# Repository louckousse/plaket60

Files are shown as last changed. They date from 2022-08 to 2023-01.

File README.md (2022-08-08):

# Plaket60
## Based on [Plain60 Flex Edition rev2.2](https://github.com/evyd13/plain60-flex-edition)

### Modification from Plain60 Flex Edition rev2.2

- Removing the speaker
- Removing the usb port
- Removing the flex cut
- Removing some compatibility in layout (keeping a Tsangan bottom row)

### Features
- Compatible with QMK Firmware and VIA Configurator (if you flash a VIA compatible .hex file)
- Required JST header for connection with daughterboard
- ESD protection and fuse
- No LEDs and no underglow
- Minimal layout support
- ISP header

### Supported layouts
Supported layouts of the Plaket60 PCB

### Bill of materials (BOM)
Amount is per PCB, multiply as needed.

| LCSC part # | Description | Value | Package  | Amount |
| --- | --- | ----- | --- | ---:|
| C49678 | Capacitor | 0.1uF | 0805 | 4 |
| C1779 | Capacitor | 4.7uF | 0805 | 1 |
| C28323 | Capacitor | 1uF | 0805 | 1 |
| C109001 | Diode | | 0805 | 64 |
| C261942 | Fuse | | 0805 | 1 |
| C17414 | Resistor | 10K | 0805 | 2 |
| C212411 | Resistor | 5.1K  | 0805 | 2 |
| C17561 | Resistor | 22 | 0805 | 2 |
| C44854 | MCU | 32U4  | QFP-44 | 1 |
| C7519 | ESD chip | | SOT23-6  | 1 |
| C341521 | Resonator | 16MHz | SMD | 1 |
| C92584 | Switch | | SMD | 1 |
| C2845363 | JST | | SMD | 1 |

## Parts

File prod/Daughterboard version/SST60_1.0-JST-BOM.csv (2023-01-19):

Comment | Designator | Footprint | LCSC
1k | R_Crystal1,R_Flash1,R_RST1 | R_0402_1005Metric | C11702
SM04B | J1 | JST_SH_SM04B-SRSS-TB_1x04-1MP_P1.00mm_Horizontal | C145956
.1u | C_1V-Decoup2,C_1V-Decoup3,C_3V-Decoup3,C_3V-Decoup4,C_3V-Decoup5,C_3V-Decoup6,C_3V-Decoup7,C_3V-Decoup8,C_3V-Decoup9,C_Flash1 | C_0402_1005Metric | C1525
10u | C_3V-Decoup1 | C_0402_1005Metric | C15525
22pF | C_Crystal1,C_Crystal2 | C_0402_1005Metric | C1555
RP2040 | U1 | RP2040-QFN-56 | C2040
220 | R_LED1,R_LED2 | R_0402_1005Metric | C25091
27 | R_DATA1,R_DATA2 | R_0402_1005Metric | C25100
Boot | SW1,SW2 | SW_SPST_TL3342 | C318884
1u | C_1V-Decoup1,C_3V-Decoup2,C_LDO1,C_LDO2 | C_0402_1005Metric | C52923
XC6206PxxxMR | U3 | SOT-23 | C5446
D_Small | D1,D10,D11,D12,D13,D14,D15,D16,D17,D18,D19,D2,D20,D21,D22,D23,D24,D25,D26,D27,D28,D29,D3,D30,D31,D32,D33,D34,D35,D36,D37,D38,D39,D4,D40,D41,D42,D43,D44,D45,D46,D47,D48,D49,D5,D50,D51,D52,D53,D54,D55,D56,D57,D58,D59,D6,D60,D61,D62,D63,D64,D65,D66,D67,D68,D7,D8,D9 | D_SOD-123 | C64898
74AHCT1G125 | U5 | SOT-23-5 | C7468
12MHz | Y1 | Crystal_SMD_3225-4Pin_3.2x2.5mm | C9002
WS2812B-2020 | D69,D70,D71,D72,D73,D74,D75,D76,D77,D78,D79,D80,D81,D82,D83,D84 | LED_WS2812_2020 | C965555
W25Q128JVS | U2 | SOIC-8_5.23x5.23mm_P1.27mm | C97521

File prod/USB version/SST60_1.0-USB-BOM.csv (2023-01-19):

Comment | Designator | Footprint | LCSC
1k | R_Crystal1,R_Flash1,R_RST1 | R_0402_1005Metric | C11702
PRTR5V0U2X | U4 | SOT143B | C12333
.1u | C_1V-Decoup2,C_1V-Decoup3,C_3V-Decoup3,C_3V-Decoup4,C_3V-Decoup5,C_3V-Decoup6,C_3V-Decoup7,C_3V-Decoup8,C_3V-Decoup9,C_Flash1 | C_0402_1005Metric | C1525
4.7n | C_Shield1 | C_0402_1005Metric | C1538
10u | C_3V-Decoup1 | C_0402_1005Metric | C15525
22pF | C_Crystal1,C_Crystal2 | C_0402_1005Metric | C1555
HRO-TYPE-C-31-M-12 | USB1 | HRO-TYPE-C-31-M-12-Assembly | C165948
RP2040 | U1 | RP2040-QFN-56 | C2040
220 | R_LED1,R_LED2 | R_0402_1005Metric | C25091
27 | R_DATA1,R_DATA2 | R_0402_1005Metric | C25100
5k1 | R_USB1,R_USB2 | R_0402_1005Metric | C25905
1M | R_Shield1 | R_0402_1005Metric | C26083
Boot | SW1,SW2 | SW_SPST_TL3342 | C318884
1u | C_1V-Decoup1,C_3V-Decoup2,C_LDO1,C_LDO2 | C_0402_1005Metric | C52923
XC6206PxxxMR | U3 | SOT-23 | C5446
D_Small | D1,D10,D11,D12,D13,D14,D15,D16,D17,D18,D19,D2,D20,D21,D22,D23,D24,D25,D26,D27,D28,D29,D3,D30,D31,D32,D33,D34,D35,D36,D37,D38,D39,D4,D40,D41,D42,D43,D44,D45,D46,D47,D48,D49,D5,D50,D51,D52,D53,D54,D55,D56,D57,D58,D59,D6,D60,D61,D62,D63,D64,D65,D66,D67,D68,D7,D8,D9 | D_SOD-123 | C64898
74AHCT1G125 | U5 | SOT-23-5 | C7468
500mA | F1 | Fuse_0805_2012Metric | C883103
12MHz | Y1 | Crystal_SMD_3225-4Pin_3.2x2.5mm | C9002
WS2812B-2020 | D69,D70,D71,D72,D73,D74,D75,D76,D77,D78,D79,D80,D81,D82,D83,D84 | LED_WS2812_2020 | C965555
W25Q128JVS | U2 | SOIC-8_5.23x5.23mm_P1.27mm | C97521

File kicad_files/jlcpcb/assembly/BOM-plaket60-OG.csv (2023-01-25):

Comment | Designator | Footprint | LCSC
1k | R_Crystal1,R_Flash1,R_RST1 | R_0402_1005Metric | C11702
PRTR5V0U2X | U4 | SOT143B | C12333
SM04B | J1 | JST_SH_SM04B-SRSS-TB_1x04-1MP_P1.00mm_Horizontal | C145956
.1u | C_1V-Decoup2,C_1V-Decoup3,C_3V-Decoup3,C_3V-Decoup4,C_3V-Decoup5,C_3V-Decoup6,C_3V-Decoup7,C_3V-Decoup8,C_3V-Decoup9,C_Flash1 | C_0402_1005Metric | C1525
10u | C_3V-Decoup1 | C_0402_1005Metric | C15525
22pF | C_Crystal1,C_Crystal2 | C_0402_1005Metric | C1555
RP2040 | U1 | RP2040-QFN-56 | C2040
27 | R_DATA1,R_DATA2 | R_0402_1005Metric | C25100
1u | C_1V-Decoup1,C_3V-Decoup2,C_LDO1,C_LDO2 | C_0402_1005Metric | C52923
XC6206PxxxMR | U3 | SOT-23 | C5446
D_Small | D1,D10,D11,D12,D13,D14,D15,D16,D17,D18,D19,D2,D20,D21,D22,D23,D25,D26,D27,D28,D3,D30,D31,D32,D33,D34,D35,D36,D37,D38,D39,D4,D40,D41,D42,D43,D44,D45,D46,D48,D49,D5,D50,D51,D53,D54,D55,D56,D57,D58,D59,D6,D60,D61,D62,D63,D64,D65,D66,D67,D68,D7,D8,D9 | D_SOD-123 | C64898
500mA | F1 | Fuse_0805_2012Metric | C883103
12MHz | Y1 | Crystal_SMD_3225-4Pin_3.2x2.5mm | C9002
W25Q128JVS | U2 | SOIC-8_5.23x5.23mm_P1.27mm | C97521
MX-NoLED | MX42 | mx_7u

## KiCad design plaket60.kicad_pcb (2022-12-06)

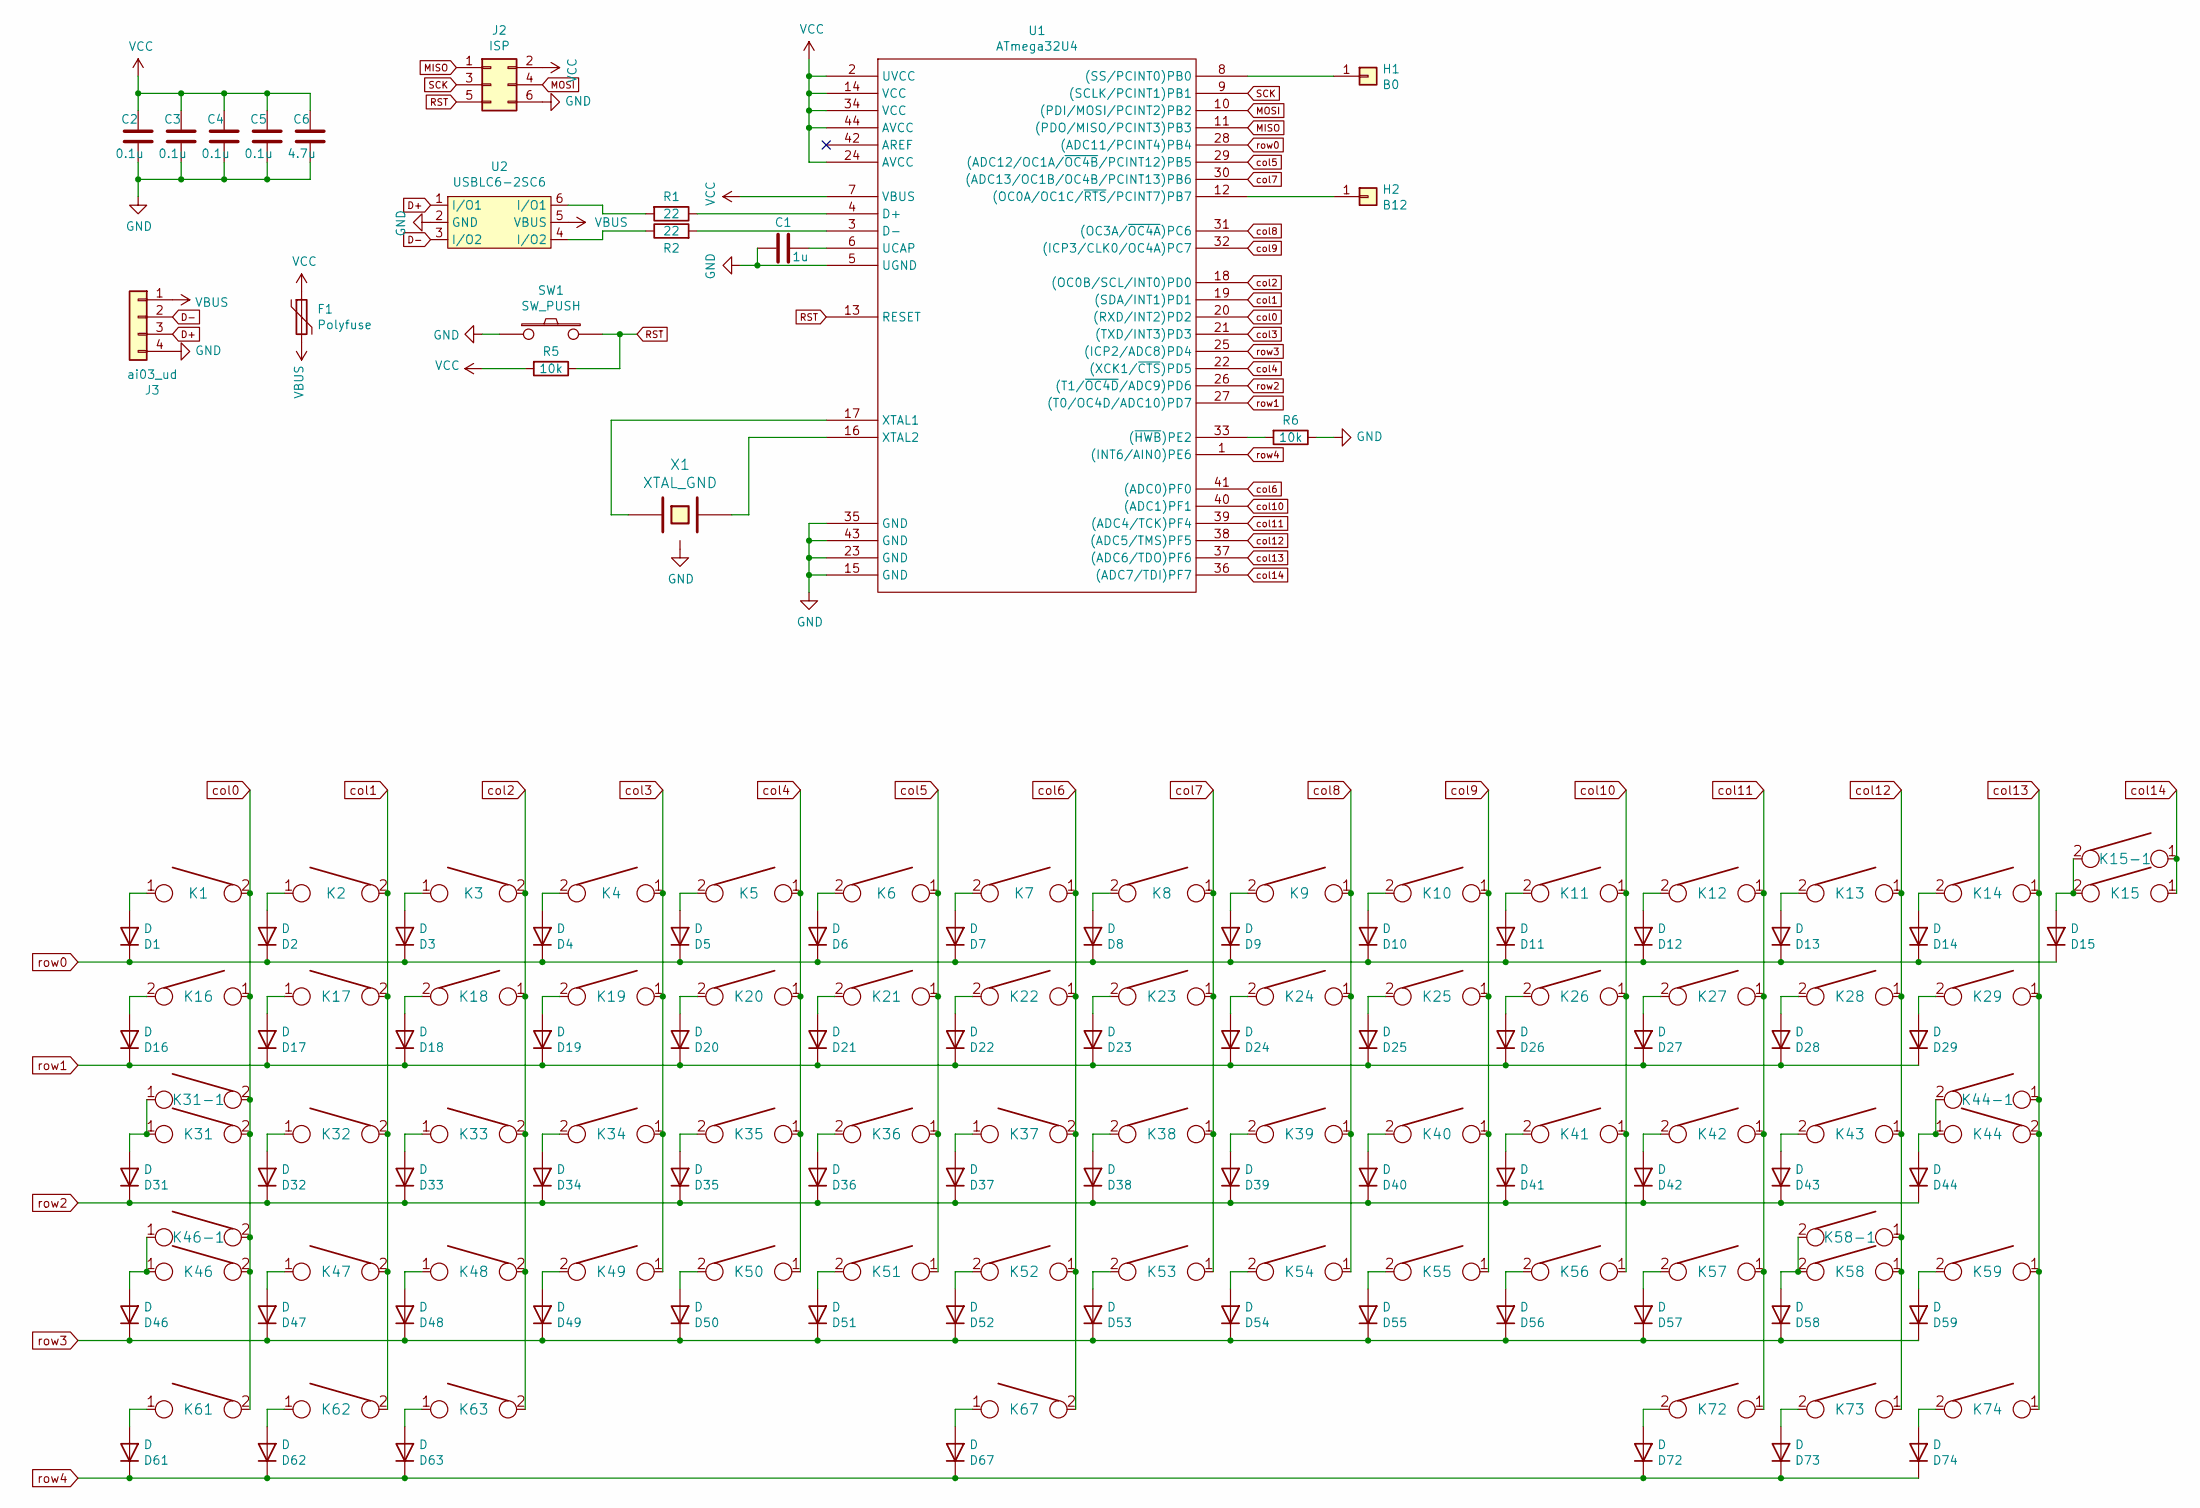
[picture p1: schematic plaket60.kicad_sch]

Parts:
C1: 1u; C_0805
C2, C3, C4, C5: 0.1u; C_0805
C6: 4.7u; C_0805
D1, D2, D3, D4, D5, D6, D7, D8, D9, D10, D11, D12, D13, D14, D15, D16, D17, D18, D19, D20, D21, D22, D23, D24, D25, D26, D27, D28, D29, D31, D32, D33, D34, D35, D36, D37, D38, D39, D40, D41, D42, D43, D44, D46, D47, D48, D49, D50, D51, D52, D53, D54, D55, D56, D57, D58, D59, D61, D62, D63, D67, D72, D73, D74: D; D_0805
F1: Polyfuse; R_0805
H1: B0; free_pin
H2: B12; free_pin
J2: ISP; isp_standard
J3: ai03_ud; JST_SH_SM04B-SRSS-TB_1x04-1MP_P1.00mm_Horizontal
K1, K2, K3, K4, K5, K6, K7, K8, K9, K10, K11, K12, K13, K14, K15-1, K17, K18, K19, K20, K21, K22, K23, K24, K25, K26, K27, K28, K32, K33, K34, K35, K36, K37, K38, K39, K40, K41, K42, K43, K47, K48, K49, K50, K51, K52, K53, K54, K55, K56, K57, K59, K62, K73: KEYSW; CHERRY_PLATE_100H
K15: KEYSW; CHERRY_PCB_200H
K16, K29, K61, K63, K72, K74: KEYSW; CHERRY_PLATE_150H
K31, K58-1: KEYSW; CHERRY_PLATE_175H
K31-1, K46-1: KEYSW; CHERRY_PLATE_125H
K44: KEYSW; CHERRY_PCB_225H_F
K44-1: KEYSW; CHERRY_PCB_200H_V
K46: KEYSW; CHERRY_PCB_225H
K58: KEYSW; CHERRY_PCB_275H
K67: KEYSW; CHERRY_PCB_700H_F
R1, R2: 22; R_0805
R5, R6: 10k; R_0805
SW1: SW_PUSH; SW_SPST_TL3342
U1: ATmega32U4; ATMEGA32U4
U2: USBLC6-2SC6; Farnell 1295310
X1: XTAL_GND; Resonator_SMD_muRata_CSTNExxV-3Pin-p1.2

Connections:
D+: J3.3, U2.1 (I/O1)
D-: J3.2, U2.3 (I/O2)
GND: C1.2, C2.1, C3.1, C4.1, C5.1, C6.1, J2.6, J3.4, R6.1, SW1.1, U1.5 (UGND), U1.15 (GND), U1.23 (GND), U1.35 (GND), U1.43 (GND), U2.2 (GND), X1.3
MISO: J2.1, U1.11 ((PDO/MISO/PCINT3)PB3)
MOSI: J2.4, U1.10 ((PDI/MOSI/PCINT2)PB2)
unnamed: C1.1, U1.6 (UCAP)
unnamed: D1.2 (A), K1.1
unnamed: D2.2 (A), K2.1
unnamed: D3.2 (A), K3.1
unnamed: D4.2 (A), K4.2
unnamed: D5.2 (A), K5.2
unnamed: D6.2 (A), K6.2
unnamed: D7.2 (A), K7.2
unnamed: D8.2 (A), K8.2
unnamed: D9.2 (A), K9.2
unnamed: D10.2 (A), K10.2
unnamed: D11.2 (A), K11.2
unnamed: D12.2 (A), K12.2
unnamed: D13.2 (A), K13.2
unnamed: D14.2 (A), K14.2
unnamed: D15.2 (A), K15.2, K15-1.2
unnamed: D16.2 (A), K16.2
unnamed: D17.2 (A), K17.1
unnamed: D18.2 (A), K18.2
unnamed: D19.2 (A), K19.2
unnamed: D20.2 (A), K20.2
unnamed: D21.2 (A), K21.2
unnamed: D22.2 (A), K22.2
unnamed: D23.2 (A), K23.2
unnamed: D24.2 (A), K24.2
unnamed: D25.2 (A), K25.2
unnamed: D26.2 (A), K26.2
unnamed: D27.2 (A), K27.2
unnamed: D28.2 (A), K28.2
unnamed: D29.2 (A), K29.2
unnamed: D31.2 (A), K31.1, K31-1.1
unnamed: D32.2 (A), K32.1
unnamed: D33.2 (A), K33.1
unnamed: D34.2 (A), K34.2
unnamed: D35.2 (A), K35.2
unnamed: D36.2 (A), K36.2
unnamed: D37.2 (A), K37.1
unnamed: D38.2 (A), K38.2
unnamed: D39.2 (A), K39.2
unnamed: D40.2 (A), K40.2
unnamed: D41.2 (A), K41.2
unnamed: D42.2 (A), K42.2
unnamed: D43.2 (A), K43.2
unnamed: D44.2 (A), K44.1, K44-1.2
unnamed: D46.2 (A), K46.1, K46-1.1
unnamed: D47.2 (A), K47.1
unnamed: D48.2 (A), K48.1
unnamed: D49.2 (A), K49.2
unnamed: D50.2 (A), K50.2
unnamed: D51.2 (A), K51.2
unnamed: D52.2 (A), K52.2
unnamed: D53.2 (A), K53.2
unnamed: D54.2 (A), K54.2
unnamed: D55.2 (A), K55.2
unnamed: D56.2 (A), K56.2
unnamed: D57.2 (A), K57.2
unnamed: D58.2 (A), K58.2, K58-1.2
unnamed: D59.2 (A), K59.2
unnamed: D61.2 (A), K61.1
unnamed: D62.2 (A), K62.1
unnamed: D63.2 (A), K63.1
unnamed: D67.2 (A), K67.1
unnamed: D72.2 (A), K72.2
unnamed: D73.2 (A), K73.2
unnamed: D74.2 (A), K74.2
unnamed: H1.1, U1.8 ((SS/PCINT0)PB0)
unnamed: H2.1, U1.12 ((OC0A/OC1C/~RTS/PCINT7)PB7)
unnamed: R1.1, U1.4 (D+)
unnamed: R1.2, U2.6 (I/O1)
unnamed: R2.1, U2.4 (I/O2)
unnamed: R2.2, U1.3 (D-)
unnamed: R6.2, U1.33 ((~HWB)PE2)
unnamed: U1.16 (XTAL2), X1.2
unnamed: U1.17 (XTAL1), X1.1
RST: J2.5, R5.1, SW1.2, U1.13 (RESET)
SCK: J2.3, U1.9 ((SCLK/PCINT1)PB1)
VBUS: F1.2, J3.1, U2.5 (VBUS)
VCC: C2.2, C3.2, C4.2, C5.2, C6.2, F1.1, J2.2, R5.2, U1.2 (UVCC), U1.7 (VBUS), U1.14 (VCC), U1.24 (AVCC), U1.34 (VCC), U1.44 (AVCC)
col0: K1.2, K16.1, K31.2, K31-1.2, K46.2, K46-1.2, K61.2, U1.20 ((RXD/INT2)PD2)
col1: K2.2, K17.2, K32.2, K47.2, K62.2, U1.19 ((SDA/INT1)PD1)
col2: K3.2, K18.1, K33.2, K48.2, K63.2, U1.18 ((OC0B/SCL/INT0)PD0)
col3: K4.1, K19.1, K34.1, K49.1, U1.21 ((TXD/INT3)PD3)
col4: K5.1, K20.1, K35.1, K50.1, U1.22 ((XCK1/~CTS)PD5)
col5: K6.1, K21.1, K36.1, K51.1, U1.29 ((ADC12/OC1A/~OC4B/PCINT12)PB5)
col6: K7.1, K22.1, K37.2, K52.1, K67.2, U1.41 ((ADC0)PF0)
col7: K8.1, K23.1, K38.1, K53.1, U1.30 ((ADC13/OC1B/OC4B/PCINT13)PB6)
col8: K9.1, K24.1, K39.1, K54.1, U1.31 ((OC3A/~OC4A)PC6)
col9: K10.1, K25.1, K40.1, K55.1, U1.32 ((ICP3/CLK0/OC4A)PC7)
col10: K11.1, K26.1, K41.1, K56.1, U1.40 ((ADC1)PF1)
col11: K12.1, K27.1, K42.1, K57.1, K72.1, U1.39 ((ADC4/TCK)PF4)
col12: K13.1, K28.1, K43.1, K58.1, K58-1.1, K73.1, U1.38 ((ADC5/TMS)PF5)
col13: K14.1, K29.1, K44.2, K44-1.1, K59.1, K74.1, U1.37 ((ADC6/TDO)PF6)
col14: K15.1, K15-1.1, U1.36 ((ADC7/TDI)PF7)
row0: D1.1 (K), D2.1 (K), D3.1 (K), D4.1 (K), D5.1 (K), D6.1 (K), D7.1 (K), D8.1 (K), D9.1 (K), D10.1 (K), D11.1 (K), D12.1 (K), D13.1 (K), D14.1 (K), D15.1 (K), U1.28 ((ADC11/PCINT4)PB4)
row1: D16.1 (K), D17.1 (K), D18.1 (K), D19.1 (K), D20.1 (K), D21.1 (K), D22.1 (K), D23.1 (K), D24.1 (K), D25.1 (K), D26.1 (K), D27.1 (K), D28.1 (K), D29.1 (K), U1.27 ((T0/OC4D/ADC10)PD7)
row2: D31.1 (K), D32.1 (K), D33.1 (K), D34.1 (K), D35.1 (K), D36.1 (K), D37.1 (K), D38.1 (K), D39.1 (K), D40.1 (K), D41.1 (K), D42.1 (K), D43.1 (K), D44.1 (K), U1.26 ((T1/~OC4D/ADC9)PD6)
row3: D46.1 (K), D47.1 (K), D48.1 (K), D49.1 (K), D50.1 (K), D51.1 (K), D52.1 (K), D53.1 (K), D54.1 (K), D55.1 (K), D56.1 (K), D57.1 (K), D58.1 (K), D59.1 (K), U1.25 ((ICP2/ADC8)PD4)
row4: D61.1 (K), D62.1 (K), D63.1 (K), D67.1 (K), D72.1 (K), D73.1 (K), D74.1 (K), U1.1 ((INT6/AIN0)PE6)

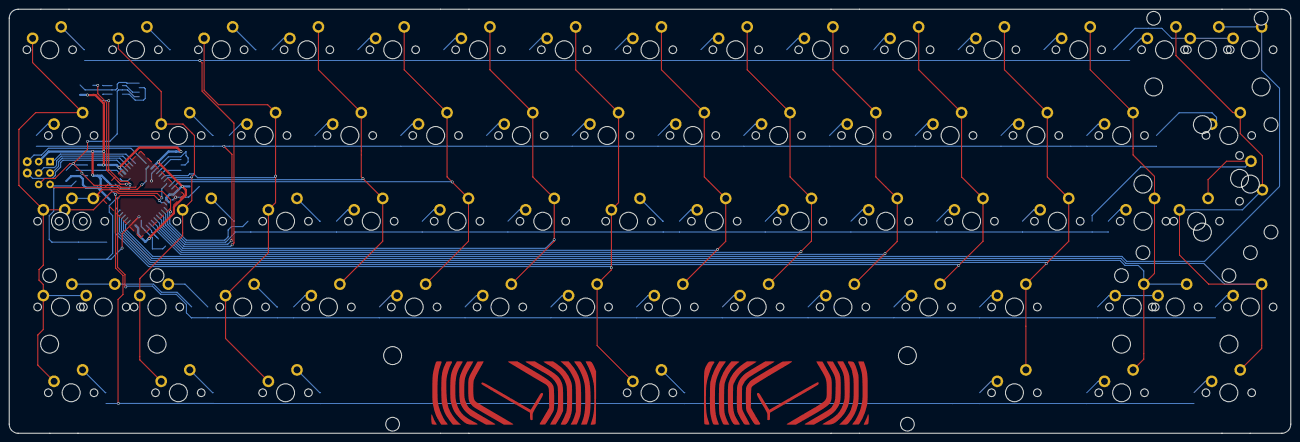
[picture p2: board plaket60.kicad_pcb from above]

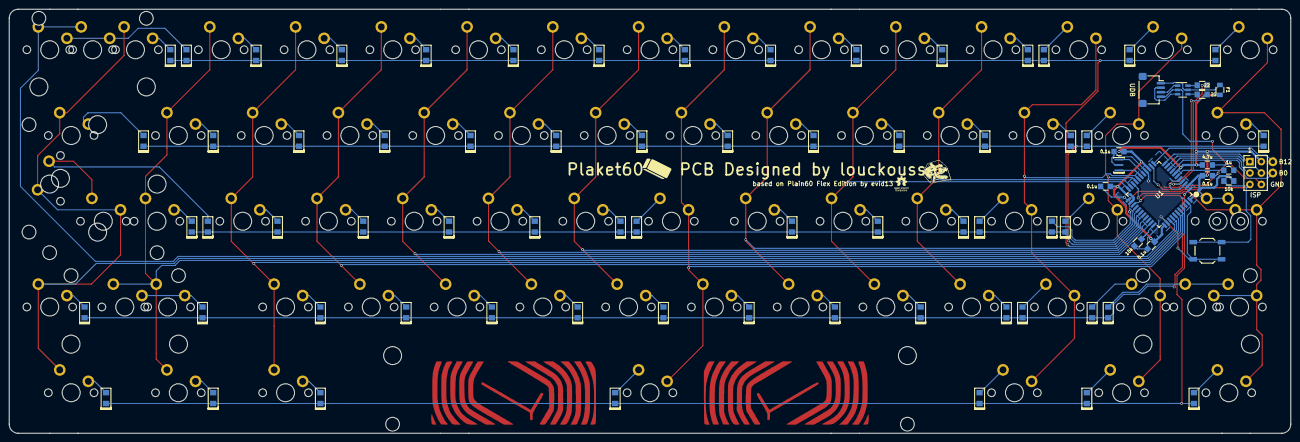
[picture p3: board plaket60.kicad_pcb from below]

Board: 2 copper layers, 284.7 x 94.2 mm, 152 parts (83 on the bottom side), 103 nets.

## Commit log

2022-12-06 last commit on atmega32u4
    [plaket60.kicad_pcb]
2023-01-25 go to jlcpcb
    [BOM-plaket60-OG.csv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]
2023-02-10 ready for GB
    [POS-plaket60-OG.csv, plaket60-OG-CuBottom.gbr, plaket60-OG-CuTop.gbr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]
